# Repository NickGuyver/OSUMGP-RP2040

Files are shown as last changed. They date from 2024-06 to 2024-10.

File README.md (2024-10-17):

# OSUMGP-RP2040

**OSUMGP-RP2040**: **Open Source Universal Modern Game Pad - RP2040 Edition**. This project is a reference design for building a game pad utilizing the GP2040-CE firmware, specifically tailored for the RP2040 microcontroller.

KiCanvas link so you don't have to download to just review the files is [here](https://kicanvas.org/?github=https%3A%2F%2Fgithub.com%2FNickGuyver%2FOSUMGP-RP2040)

## Current Status
- **Beta**: The project is currently in beta. Feedback and contributions to improve the design and functionality are appreciated.
- **Case**: [RAF](https://github.com/RAF-no-desu) generously created a 3D printable case [here](https://www.printables.com/model/1000656-universal-modern-game-pad-w-usb-passthrough-osumgp)
- **Firmware**: Latest release of GP2040-CE firmware is [here](https://github.com/OpenStickCommunity/GP2040-CE/releases/latest/download/GP2040-CE_0.7.10_OSUMGP-RP2040.uf2)

## Features
- **Open Source**: Fully open-source design and firmware for community collaboration and customization.
- **RP2040 Microcontroller**: Leverages the powerful and versatile RP2040, the same chip used in the Raspberry Pi Pico.
- **GP2040-CE Firmware**: Compatible with the GP2040-CE firmware, providing robust support for many consoles and devices.
- **Customizable**: Easily adaptable for various game pad layouts and configurations.

## Pinout Summary
- See [GP2040-CE Usage](https://gp2040-ce.info/usage/) for reference between modes

| RP2040 Pin | Action | PCB |
|---|---|---|
| 17 | Up | S4 |
| 13 | Down | S1 |
| 14 | Right | S2 |
| 16 | Left | S3 |
| 9 | B1 | S5 |
| 8 | B2 | S6 |
| 7 | R2 | S18 |
| 18 | L2 | S17 |
| 6 | B3 | S7 |
| 5 | B4 | S8 |
| 3 | R1 | S16 |
| 21 | L1 | S15 |
| 22 | S1 | S9 |
| 2 | S2 | S10 |
| 19 | L3 | SW3 |
| 10 | R3 | SW4 |
| 15 | A1 | S14 |
| 20 | A2 | S11 |
| 26 | LS - X | SW3 |
| 28 | LS - Y | SW3 |
| 27 | RS - X | SW4 |
| 29 | RS - Y | SW4 |

| RP2040 Pin | Function | PCB |
|---|---|---|
| 0 | SDA | J2 |
| 1 | SCL | J2 |
| 11 | USB D+ | J3 |
| 12 | USB D- | J3 |

osumgp-rp2040_0 4b-real

## Thanks
Special thanks to the [Alpakka](https://inputlabs.io/alpakka) and [GP2040-CE](https://gp2040-ce.info/) projects, as well as the many people in the community who provided help and guidance.

## License
This project is licensed under the Creative Commons Attribution 4.0 International License - see the [LICENSE](LICENSE) file for details.

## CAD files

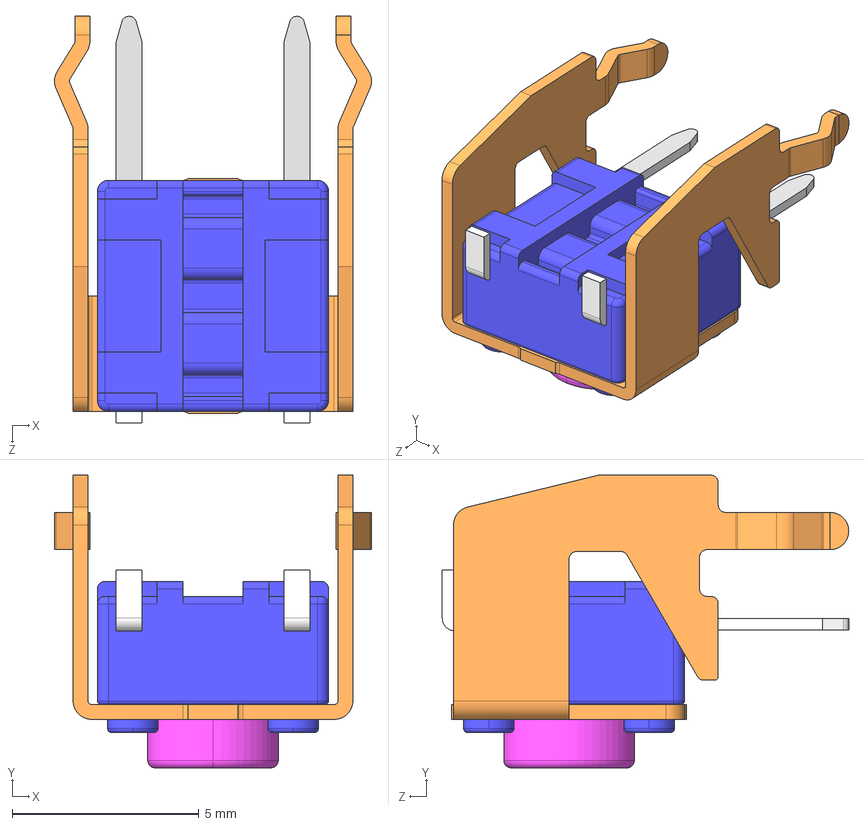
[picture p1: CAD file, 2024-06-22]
symbols/step/SKHHLN.STEP
8.50 x 7.85 x 10.9 mm

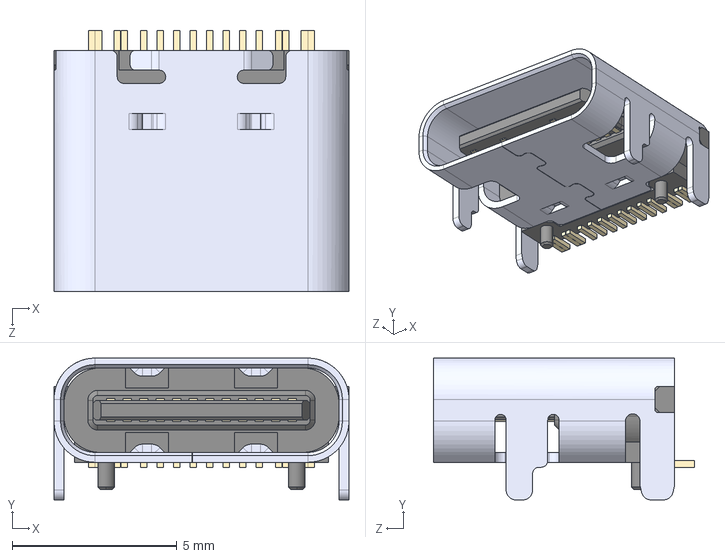
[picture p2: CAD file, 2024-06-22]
symbols/step/TYPE-C-31-M-12.step
8.94 x 4.30 x 7.90 mm

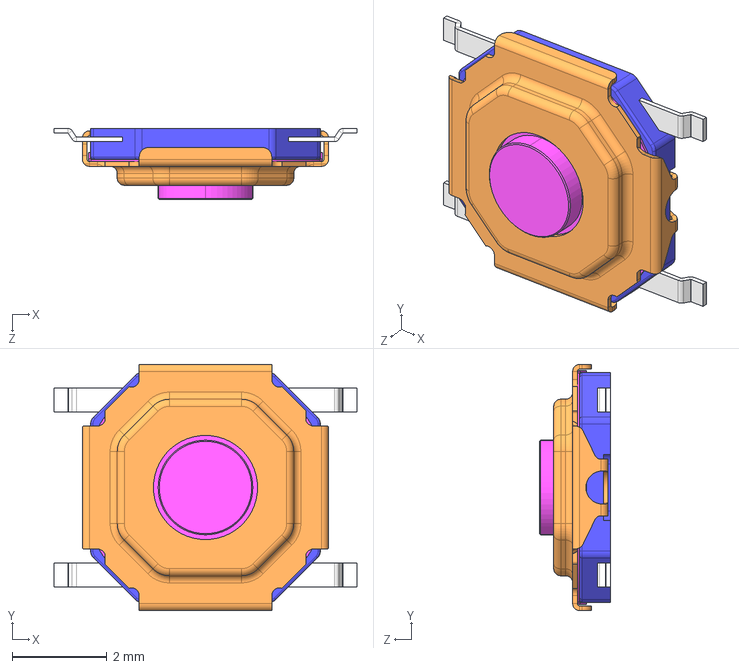
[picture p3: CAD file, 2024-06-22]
symbols/step/SKQGAF.STEP
6.40 x 5.20 x 1.50 mm

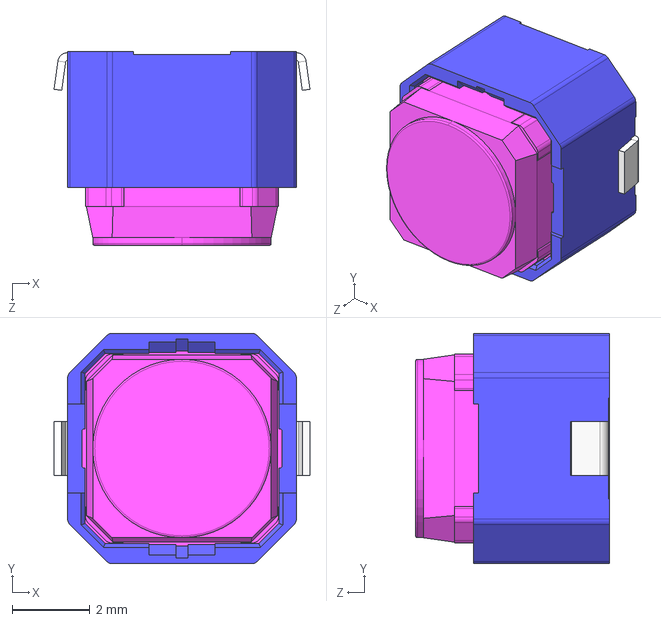
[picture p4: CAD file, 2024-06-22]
symbols/step/SKPMAM.STEP
6.60 x 5.94 x 5.00 mm

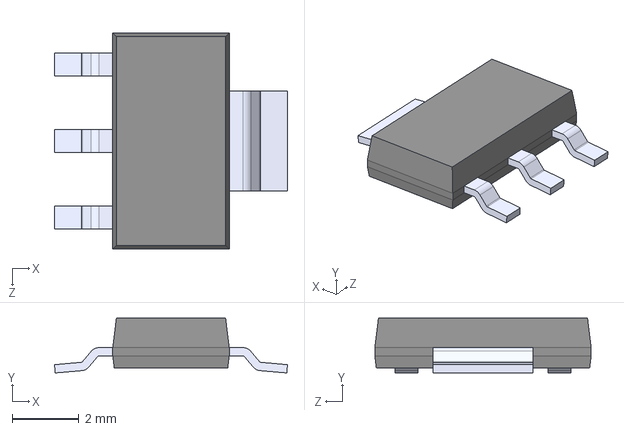
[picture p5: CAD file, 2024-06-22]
symbols/step/AP2114HA-3.3TRG1.step
7.00 x 1.65 x 6.50 mm

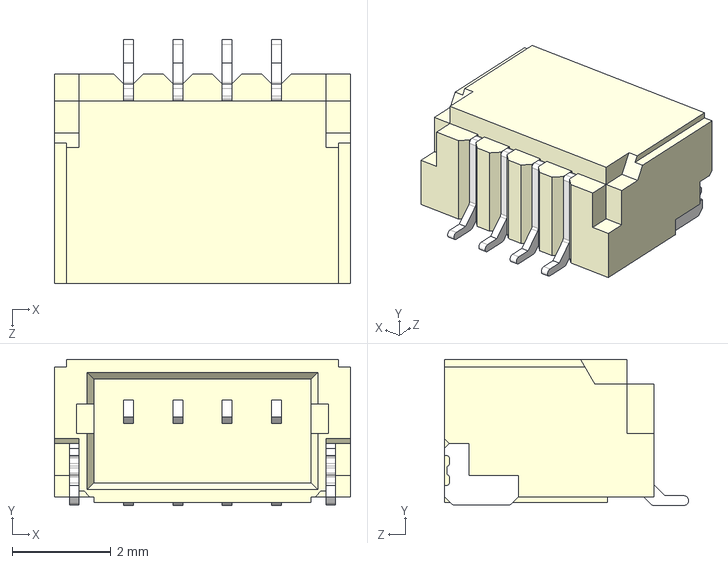
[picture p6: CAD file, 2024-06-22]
symbols/step/SM04B-SRSS-TB(LF)(SN).STEP
6.00 x 2.96 x 4.95 mm

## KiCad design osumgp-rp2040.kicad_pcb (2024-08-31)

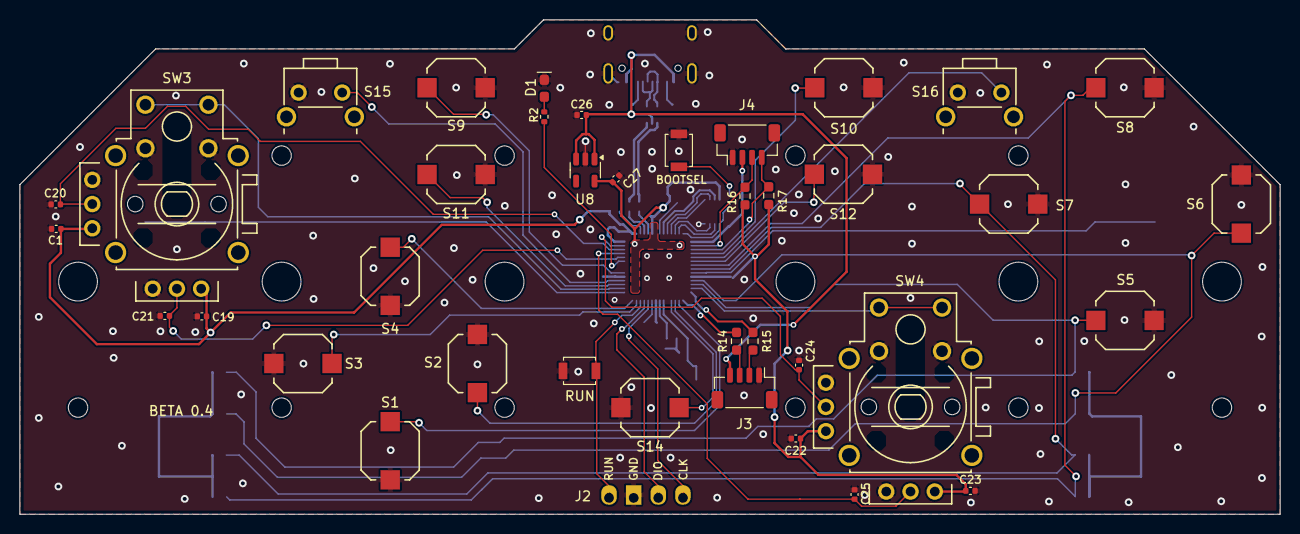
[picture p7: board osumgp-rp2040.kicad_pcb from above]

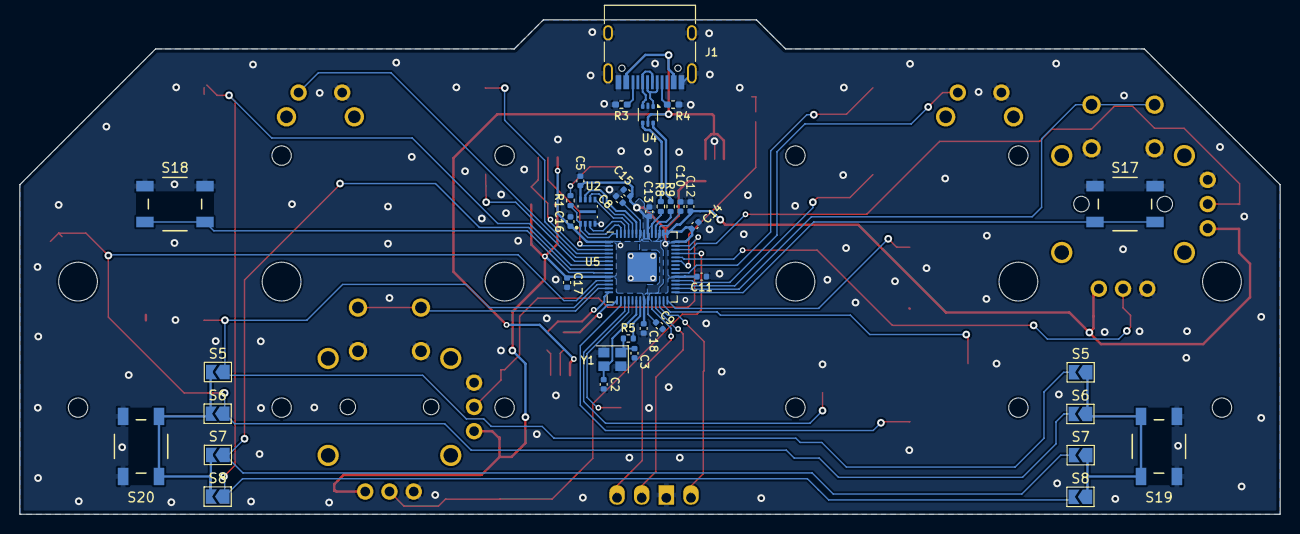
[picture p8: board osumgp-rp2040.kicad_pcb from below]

Board: 2 copper layers, 130.0 x 51.0 mm, 76 parts (37 on the bottom side), 58 nets.

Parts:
C1, C5, C8, C9, C11, C13, C14, C15, C16, C17, C18, C19, C20, C21, C22, C23, C24, C25: 100nF; C_0402_1005Metric
C2, C3: 18pF; C_0402_1005Metric
C10, C12, C26, C27: 1uF; C_0402_1005Metric
D1: LED; LED_0603_1608Metric_Pad1.05x0.95mm_HandSolder
J1: USB_C_Receptacle_USB2.0; USB_C_Receptacle_HRO_TYPE-C-31-M-12
J2: SWD; Pico_4pin
J3: USB; JST_SH_BM04B-SRSS-TB_1x04-1MP_P1.00mm_Vertical
J4: I2C; JST_SH_BM04B-SRSS-TB_1x04-1MP_P1.00mm_Vertical
JP2, JP6: S5; SolderJumper-2_P1.3mm_Open_TrianglePad1.0x1.5mm
JP3, JP7: S6; SolderJumper-2_P1.3mm_Open_TrianglePad1.0x1.5mm
JP4, JP8: S7; SolderJumper-2_P1.3mm_Open_TrianglePad1.0x1.5mm
JP5, JP9: S8; SolderJumper-2_P1.3mm_Open_TrianglePad1.0x1.5mm
R1, R2, R5: 1kΩ; R_0402_1005Metric
R3, R4: 5.1kΩ; R_0402_1005Metric_Pad0.72x0.64mm_HandSolder
R8, R9: 27Ω; R_0402_1005Metric
R14, R15: 22Ω; R_0603_1608Metric_Pad0.98x0.95mm_HandSolder
R16, R17: 2.2kΩ; R_0603_1608Metric_Pad0.98x0.95mm_HandSolder
S1, S2, S3, S4, S5, S6, S7, S8, S9, S10, S11, S12, S14: Face Button; Alpsalpine_SKPM
S15, S16: Shoulder Button; Alpsalpine_SKHHL
S17, S18, S19, S20: Back Button; Alpsalpine_SKQG
SW1: BOOTSEL; SW_SPST_B3U-1000P
SW2: RST; SW_SPST_B3U-1000P
SW3, SW4: Alpsalpine_RKJXV; Alpsalpine_RKJXV122400R
U2: W25Q16JVUXIQ; IC_W25Q16JVUXIQ_TR
U4: USBLC6-2P6; SOT-666
U5: RP2040; RP2040-QFN-56
U8: AP2112K-3.3; SOT-23-5
Y1: ECS-120-12-36-AGN-TR3; Crystal_SMD_2520-4Pin_2.5x2.0mm

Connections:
+1V1: C8.1, C9.1, C10.1, U5.23 (DVDD), U5.45 (VREG_VOUT), U5.50 (DVDD)
+3V3: C1.2, C5.1, C11.1, C12.1, C13.1, C14.1, C15.1, C16.1, C17.1, C18.1, C19.1, C22.2, C23.1, C27.1, J4.2 (3V3), R16.1, R17.1, SW3.3 (VCC0), SW3.6 (VCC1), SW4.3 (VCC0), SW4.6 (VCC1), U2.8 (VCC), U5.1 (IOVDD), U5.10 (IOVDD), U5.22 (IOVDD), U5.33 (IOVDD), U5.42 (IOVDD), U5.43 (ADC_AVDD), U5.44 (VREG_IN), U5.48 (USB_VDD), U5.49 (IOVDD), U8.5 (VOUT)
+5V: C26.1, J1.A4 (VBUS), J1.A9 (VBUS), J1.B4 (VBUS), J1.B9 (VBUS), J3.4 (VCC), U4.5 (VBUS), U8.1 (VIN), U8.3 (EN)
/BUTTON_A1: S14.2, U5.18 (GPIO15)
/BUTTON_A2: S11.2, U5.31 (GPIO20)
/BUTTON_B1: JP2.2 (B), JP6.1 (A), S5.2, U5.12 (GPIO9)
/BUTTON_B2: JP3.2 (B), JP7.1 (A), S6.2, U5.11 (GPIO8)
/BUTTON_B3: JP4.2 (B), JP8.1 (A), S7.2, U5.8 (GPIO6)
/BUTTON_B4: JP5.2 (B), JP9.1 (A), S8.2, U5.7 (GPIO5)
/BUTTON_DOWN: S1.2, U5.16 (GPIO13)
/BUTTON_L1: S15.2, U5.32 (GPIO21)
/BUTTON_L2: S17.2, U5.29 (GPIO18)
/BUTTON_L3: SW3.8 (B), SW3.10 (D), U5.30 (GPIO19)
/BUTTON_LEFT: S3.2, U5.27 (GPIO16)
/BUTTON_R1: S16.2, U5.5 (GPIO3)
/BUTTON_R2: S18.2, U5.9 (GPIO7)
/BUTTON_R3: SW4.8 (B), SW4.10 (D), U5.13 (GPIO10)
/BUTTON_RIGHT: S2.2, U5.17 (GPIO14)
/BUTTON_S1: S9.2, U5.34 (GPIO22)
/BUTTON_S2: S10.2, U5.4 (GPIO2)
/BUTTON_UP: S4.2, U5.28 (GPIO17)
/D+: R8.1, U4.4 (I/O2)
/D-: R9.1, U4.6 (I/O1)
/DN: R9.2, U5.46 (USB_DM)
/DP: R8.2, U5.47 (USB_DP)
/GPIO4: S12.2, U5.6 (GPIO4)
/GPIO25: R2.1, U5.37 (GPIO25)
/I2C0_SCL: J4.4 (SCL), R17.2, U5.3 (GPIO1)
/I2C0_SDA: J4.3 (SDA), R16.2, U5.2 (GPIO0)
/QSPI_SCLK: U2.6 (CLK), U5.52 (QSPI_SCLK)
/QSPI_SD0: U2.5 (DI(IO0)), U5.53 (QSPI_SD0)
/QSPI_SD1: U2.2 (DO(IO1)), U5.55 (QSPI_SD1)
/QSPI_SD2: U2.3 (IO2), U5.54 (QSPI_SD2)
/QSPI_SD3: U2.7 (IO3), U5.51 (QSPI_SD3)
/QSPI_SS: R1.1, U2.1 (~CS), U5.56 (QSPI_SS)
/RUN: J2.4, SW2.1, U5.26 (RUN)
/SWCLK: J2.1, U5.24 (SWCLK)
/SWD: J2.2, U5.25 (SWD)
/THUMBSTICK_LEFT_X: C21.2, SW3.5 (ADC1), U5.38 (GPIO26_ADC0)
/THUMBSTICK_LEFT_Y: C20.2, SW3.2 (ADC0), U5.40 (GPIO28_ADC2)
/THUMBSTICK_RIGHT_X: C25.2, SW4.5 (ADC1), U5.39 (GPIO27_ADC1)
/THUMBSTICK_RIGHT_Y: C24.2, SW4.2 (ADC0), U5.41 (GPIO29_ADC3)
/USBD+: J1.A6 (D+), J1.B6 (D+), U4.3 (I/O2)
/USBD-: J1.A7 (D-), J1.B7 (D-), U4.1 (I/O1)
/USBH_DN: R14.2, U5.15 (GPIO12)
/USBH_DP: R15.1, U5.14 (GPIO11)
/XIN: C2.1, U5.20 (XIN), Y1.3
/XOUT: R5.1, U5.21 (XOUT)
GND: C1.1, C2.2, C3.2, C5.2, C8.2, C9.2, C10.2, C11.2, C12.2, C13.2, C14.2, C15.2, C16.2, C17.2, C18.2, C19.2, C20.1, C21.1, C22.1, C23.2, C24.1, C25.1, C26.2, C27.2, D1.1 (K), J1.A1 (GND), J1.A12 (GND), J1.B1 (GND), J1.B12 (GND), J1.S1 (SHIELD), J2.3, J3.1 (GND), J4.1 (GND), R3.2, R4.2, S1.1, S2.1, S3.1, S4.1, S5.1, S6.1, S7.1, S8.1, S9.1, S10.1, S11.1, S12.1, S14.1, S15.1, S16.1, S17.1, S18.1, S19.1, S20.1, SW1.1, SW2.2, SW3.1 (GND0), SW3.4 (GND1), SW3.7 (A), SW3.9 (C), SW4.1 (GND0), SW4.4 (GND1), SW4.7 (A), SW4.9 (C), U2.4 (GND), U4.2 (GND), U5.19 (TESTEN), U5.57 (GND), U8.2 (GND), Y1.2, Y1.4
unnamed: C3.1, R5.2, Y1.1
unnamed: D1.2 (A), R2.2
unnamed: J1.A5 (CC1), R4.1
unnamed: J1.B5 (CC2), R3.1
unnamed: J3.2 (D+), R15.2
unnamed: J3.3 (D-), R14.1
unnamed: JP2.1 (A), JP3.1 (A), JP4.1 (A), JP5.1 (A), S19.2
unnamed: JP6.2 (B), JP7.2 (B), JP8.2 (B), JP9.2 (B), S20.2
unnamed: R1.2, SW1.2

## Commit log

2024-06-24 Adust trace widths, component placement, and routing to pass DRC
    [osumgp-rp2040.kicad_pcb]
2024-06-24 fix edge cut
    [osumgp-rp2040.kicad_pcb]
2024-07-20 beta 0.4
    - copper to edge clearance 0.38mm
    - fix thin +3.3V traces
    - add more GND around the RP2040
    - connected mounting pads to GND
    - add more GND stitching
    - reduce plane fingers
    - reduce top/bottom traces running in parallel
    [osumgp-rp2040.kicad_pcb, osumgp-rp2040.kicad_sch]
2024-08-31 fix led
    [osumgp-rp2040.kicad_pcb, osumgp-rp2040.kicad_sch]
